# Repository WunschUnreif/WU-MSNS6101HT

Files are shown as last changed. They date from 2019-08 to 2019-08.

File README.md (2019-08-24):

# WU-MSNS6101HT

A module based on motion sensor MPU-6050 with a controllable heater to provide a constant working temperature.

The project uses KiCad for schematic and PCB drawing.

---
<br />This work is licensed under a <a rel="license" href="http://creativecommons.org/licenses/by/4.0/">Creative Commons Attribution 4.0 International License</a>.

---

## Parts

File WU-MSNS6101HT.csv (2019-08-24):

Reference | Quantity | Value | Footprint | Datasheet | Category | DK_Datasheet_Link | DK_Detail_Page | Description | Digi-Key_PN | Family | MPN | Manufacturer | Status
C1 | 1 | 10uF | Capacitor_Tantalum_SMD:CP_EIA-3216-10_Kemet-I_Pad1.58x1.35mm_HandSolder | ~
C2 | 1 | 10nF | Capacitor_SMD:C_0805_2012Metric_Pad1.15x1.40mm_HandSolder | ~
C4 C3 | 2 | 100nF | Capacitor_SMD:C_0805_2012Metric_Pad1.15x1.40mm_HandSolder | ~
C5 | 1 | 2.2nF | Capacitor_SMD:C_0805_2012Metric_Pad1.15x1.40mm_HandSolder | ~
D1 | 1 | GREEN | LED_SMD:LED_0805_2012Metric_Pad1.15x1.40mm_HandSolder | ~
D2 | 1 | YELLOW | LED_SMD:LED_0805_2012Metric_Pad1.15x1.40mm_HandSolder | ~
D3 | 1 | RED | LED_SMD:LED_0805_2012Metric_Pad1.15x1.40mm_HandSolder | ~
J1 J2 | 2 | Conn_01x04 | Connector_PinSocket_2.54mm:PinSocket_1x04_P2.54mm_Vertical | ~
Q1 Q2 | 2 | AO3400A | digikey-footprints:SOT-23-3 | https://www.onsemi.com/pub/Collateral/NDS7002A-D.PDF | Discrete Semiconductor Products | https://www.onsemi.com/pub/Collateral/NDS7002A-D.PDF | /product-detail/en/on-semiconductor/2N7002/2N7002NCT-ND/244664 | MOSFET N-CH 60V 115MA SOT-23 | 2N7002NCT-ND | Transistors - FETs, MOSFETs - Single | 2N7002 | ON Semiconductor | Active
R1 R9 R8 R13 R14 | 5 | 4.7k | Resistor_SMD:R_0805_2012Metric_Pad1.15x1.40mm_HandSolder | ~
R10 | 1 | 22k | Resistor_SMD:R_0805_2012Metric_Pad1.15x1.40mm_HandSolder | ~
R11 | 1 | 100k | Resistor_SMD:R_0805_2012Metric_Pad1.15x1.40mm_HandSolder | ~
R15 | 1 | 1k | Resistor_SMD:R_0805_2012Metric_Pad1.15x1.40mm_HandSolder | ~
R2 R7 R12 | 3 | 470 | Resistor_SMD:R_0805_2012Metric_Pad1.15x1.40mm_HandSolder | ~
R3 R6 R16 | 3 | 10k | Resistor_SMD:R_0805_2012Metric_Pad1.15x1.40mm_HandSolder | ~
R4 R5 | 2 | 47 | Resistor_SMD:R_2512_6332Metric_Pad1.52x3.35mm_HandSolder | ~
TH1 | 1 | MF52 10K | Connector_PinHeader_2.54mm:PinHeader_1x02_P2.54mm_Vertical | ~
U1 | 1 | MPU-6050 | Sensor_Motion:InvenSense_QFN-24_4x4mm_P0.5mm | https://store.invensense.com/datasheets/invensense/MPU-6050_DataSheet_V3%204.pdf
U2 | 1 | LMV358 | Package_SO:SOIC-8_3.9x4.9mm_P1.27mm | http://www.ti.com/lit/ds/symlink/lmv324.pdf
U3 | 1 | 74AHC1G08 | Package_TO_SOT_SMD:SOT-23-5_HandSoldering | http://www.ti.com/lit/sg/scyt129e/scyt129e.pdf

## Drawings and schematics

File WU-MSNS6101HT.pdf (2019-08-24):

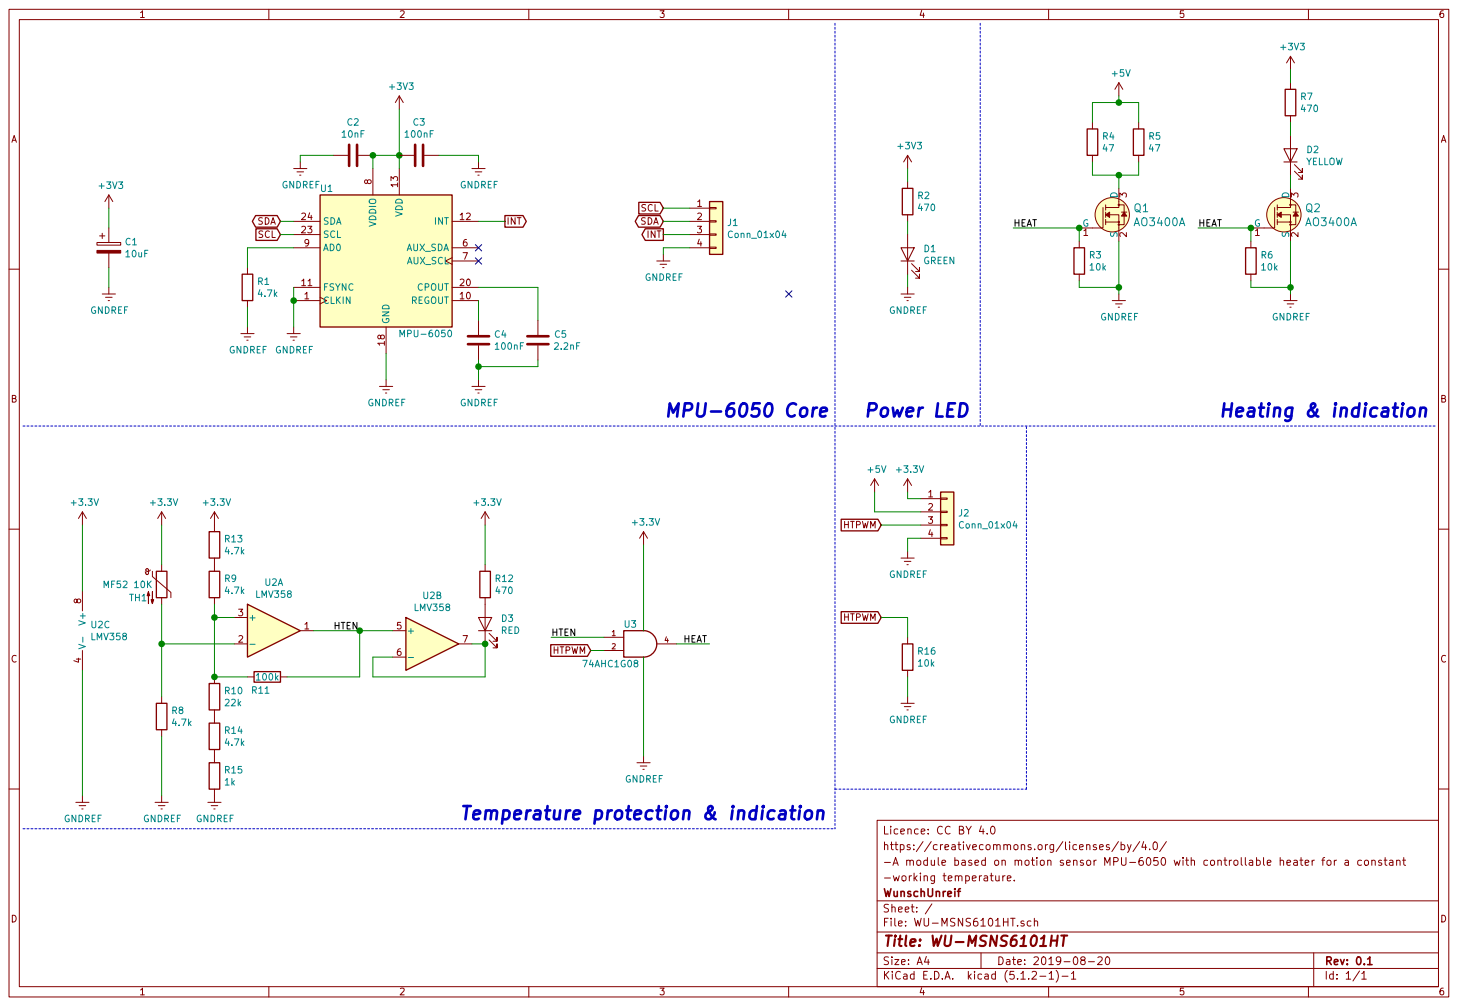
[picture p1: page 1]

+3.3V GNDREF Temperature protection & indication

-working temperature. -A module based on motion sensor MPU-6050 with controllable heater for a constant https://creativecommons.org/licenses/by/4.0/ Licence: CC BY 4.0

File: WU-MSNS6101HT.sch Sheet: / WunschUnreif

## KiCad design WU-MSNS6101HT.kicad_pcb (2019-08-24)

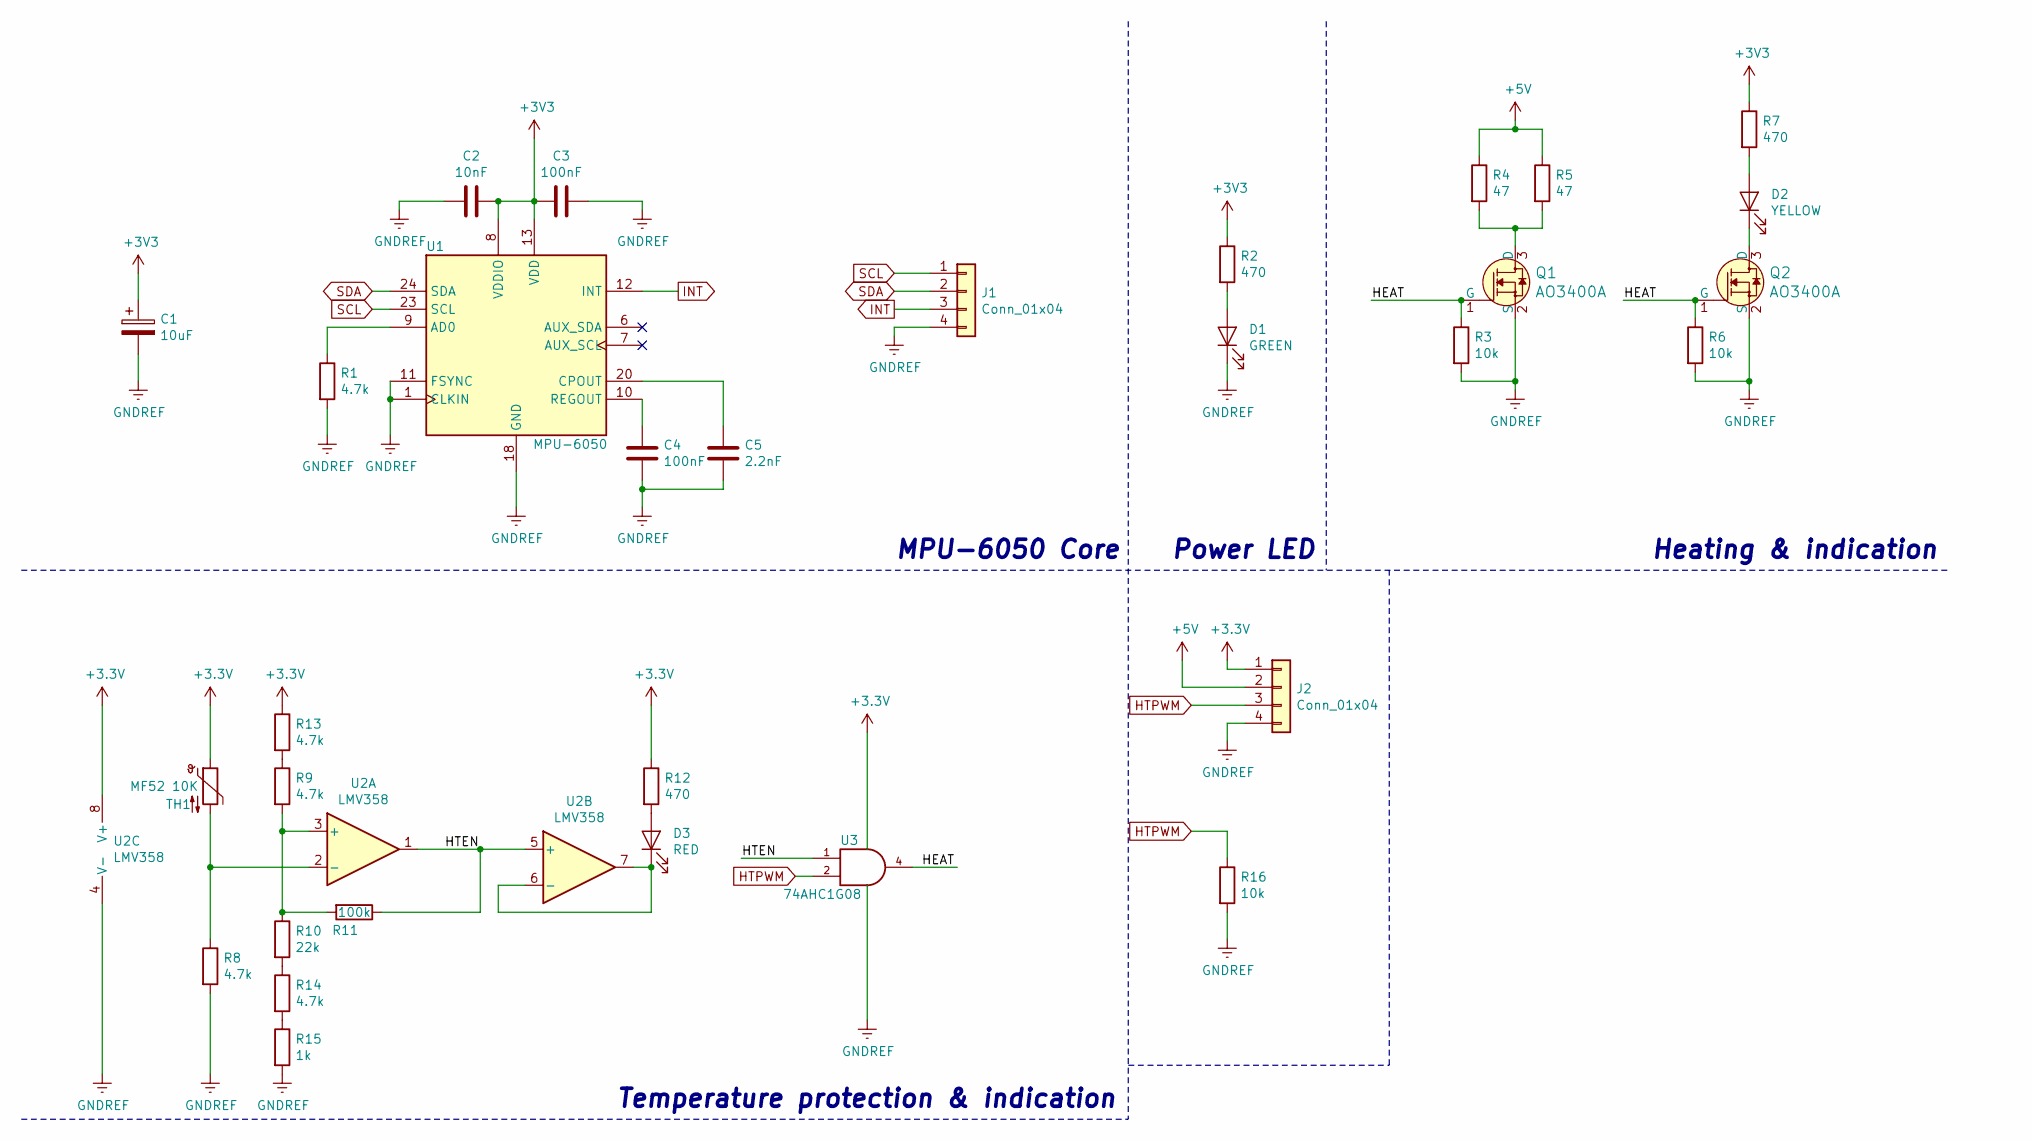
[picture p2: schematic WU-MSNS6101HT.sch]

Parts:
C1: 10uF; CP_EIA-3216-10_Kemet-I_Pad1.58x1.35mm_HandSolder
C2: 10nF; C_0805_2012Metric_Pad1.15x1.40mm_HandSolder
C3, C4: 100nF; C_0805_2012Metric_Pad1.15x1.40mm_HandSolder
C5: 2.2nF; C_0805_2012Metric_Pad1.15x1.40mm_HandSolder
D1: GREEN; LED_0805_2012Metric_Pad1.15x1.40mm_HandSolder
D2: YELLOW; LED_0805_2012Metric_Pad1.15x1.40mm_HandSolder
D3: RED; LED_0805_2012Metric_Pad1.15x1.40mm_HandSolder
J1, J2: Conn_01x04; PinSocket_1x04_P2.54mm_Vertical
Q1, Q2: AO3400A; SOT-23-3; MPN 2N7002; Digi-Key_PN 2N7002NCT-ND
R1, R8, R9, R13, R14: 4.7k; R_0805_2012Metric_Pad1.15x1.40mm_HandSolder
R2, R7, R12: 470; R_0805_2012Metric_Pad1.15x1.40mm_HandSolder
R3, R6, R16: 10k; R_0805_2012Metric_Pad1.15x1.40mm_HandSolder
R4, R5: 47; R_2512_6332Metric_Pad1.52x3.35mm_HandSolder
R10: 22k; R_0805_2012Metric_Pad1.15x1.40mm_HandSolder
R11: 100k; R_0805_2012Metric_Pad1.15x1.40mm_HandSolder
R15: 1k; R_0805_2012Metric_Pad1.15x1.40mm_HandSolder
TH1: MF52 10K; PinHeader_1x02_P2.54mm_Vertical
U1: MPU-6050; InvenSense_QFN-24_4x4mm_P0.5mm
U2: LMV358; SOIC-8_3.9x4.9mm_P1.27mm
U3: 74AHC1G08; SOT-23-5_HandSoldering

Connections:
+5V: J2.2, R4.1, R5.1
/HEAT: Q1.1 (G), Q2.1 (G), R3.1, R6.1, U3.4
/HTEN: R11.1, U2.1, U2.5 (+), U3.1
GND: C1.2, C2.2, C3.1, C4.2, C5.2, D1.1 (K), J1.4, J2.4, Q1.2 (S), Q2.2 (S), R1.2, R3.2, R6.2, R8.2, R15.2, R16.2, U1.1 (CLKIN), U1.11 (FSYNC), U1.18 (GND), U2.4 (V-), U3.3 (GND)
HTPWM: J2.3, R16.1, U3.2
INT: J1.3, U1.12 (INT)
unnamed: C4.1, U1.10 (REGOUT)
unnamed: C5.1, U1.20 (CPOUT)
unnamed: D1.2 (A), R2.2
unnamed: D2.1 (K), Q2.3 (D)
unnamed: D2.2 (A), R7.2
unnamed: D3.1 (K), U2.6 (-), U2.7
unnamed: D3.2 (A), R12.2
unnamed: Q1.3 (D), R4.2, R5.2
unnamed: R1.1, U1.9 (AD0)
unnamed: R8.1, TH1.2, U2.2 (-)
unnamed: R9.2, R10.1, R11.2, U2.3 (+)
unnamed: R10.2, R14.1
unnamed: R9.1, R13.2
unnamed: R14.2, R15.1
SCL: J1.1, U1.23 (SCL)
SDA: J1.2, U1.24 (SDA)

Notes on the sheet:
Heating & indication
Power LED
MPU-6050 Core
Temperature protection & indication

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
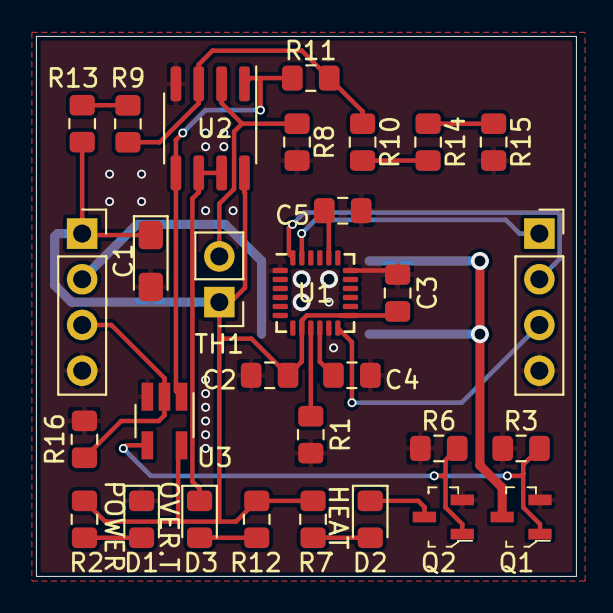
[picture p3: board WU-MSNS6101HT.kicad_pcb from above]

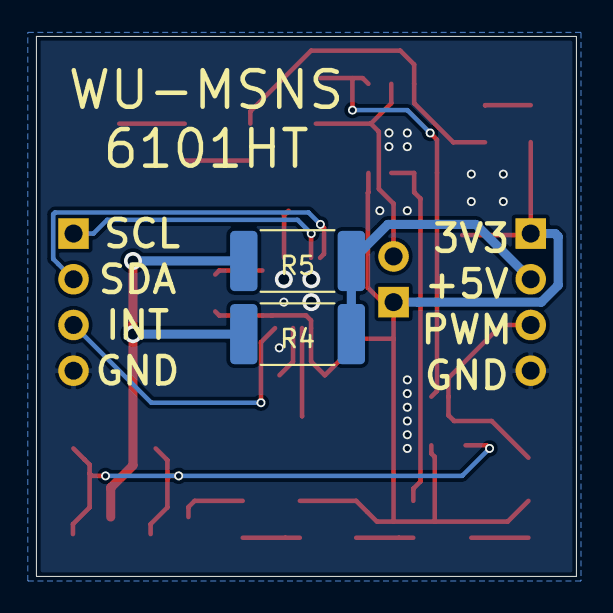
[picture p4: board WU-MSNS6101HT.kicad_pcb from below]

Board: 2 copper layers, 30.0 x 30.0 mm, 32 parts (2 on the bottom side), 23 nets.

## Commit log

2019-08-24 Add a pull down res for
    [WU-MSNS6101HT.csv, WU-MSNS6101HT.sch]
2019-08-24 Rework the PCB
    [WU-MSNS6101HT.kicad_pcb]

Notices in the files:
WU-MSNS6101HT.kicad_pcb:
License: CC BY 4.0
